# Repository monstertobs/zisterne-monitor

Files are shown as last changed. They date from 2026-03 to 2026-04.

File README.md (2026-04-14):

# 🏺 Zisterne Monitor

**Intelligente Zisternen-Wasserstandsüberwachung mit Raspberry Pi Zero 2W**

Ein vollständiges DIY-Projekt zur Überwachung des Füllstands einer Regenwasserzisterne – mit automatischer Installation, elegantem Web-Dashboard, 3D-gedrucktem Gehäuse und Wettervorhersage für den erwarteten Regenwasserzulauf.






---

## 💡 Die Idee

Ich habe eine Regenwasserzisterne im Garten, die Wasser vom Hausdach sammelt. Das Wasser wird zum Gießen und für andere Zwecke genutzt. Das Problem: Man weiß nie genau wie voll die Zisterne ist – ohne hineinzuschauen.

Die Idee war ein **vollautomatisches, selbst gehostetes Überwachungssystem** das:
- Den Wasserstand präzise misst
- Ein elegantes Dashboard im Browser zeigt
- Auf dem eigenen Heimnetzwerk läuft (keine Cloud, keine Abos)
- Komplett selbst nachgebaut werden kann

---

## ✨ Features

### Dashboard
- 🏺 **3D Erdquerschnitt** – animierte Zisterne mit Wasserstand, Blasen und Wellen
- 💧 **Liter-Anzeige** – aktueller Inhalt, Kapazität, Zu-/Abfluss seit letzter Messung
- 🔮 **Verbrauchsprognose** – wie viele Tage reicht der Vorrat noch?
- 🌧️ **Regenvorhersage** – 7-Tage-Vorhersage mit erwartetem Zulauf in Litern
- 📅 **Wochenverbrauch** – Durchschnitt pro Wochentag
- 🌧️ **Regenereignis-Erkennung** – automatische Erkennung von Regenfällen

### Installation & Betrieb
- ⚡ **Vollautomatische Installation** – SD-Karte vorbereiten, Pi einschalten, fertig
- 📡 **Captive Portal** – WLAN-Einrichtung per Smartphone wie im Hotel
- 🌐 **zisterne.local** – erreichbar über einfache URL im Heimnetz
- 📶 **WLAN-Verwaltung** – weitere Netzwerke direkt in den Einstellungen hinzufügen

### Hardware
- 🖨️ **3D-Druck Gehäuse** – für Pi Zero 2WH, druckfertige SCAD-Dateien
- 🔧 **Sensor-Halterung** – für DN25-Rohr oder Wandmontage mit Langlöchern
- 📏 **UART-Sensor** – SR04M-2 Ultraschallsensor (wasserdicht, robuste UART-Kommunikation)

---

## 🛒 Einkaufsliste

| Bauteil | Beschreibung | Preis ca. |
|---|---|---|
| Raspberry Pi Zero 2 WH | Mit vorgelötetem GPIO-Header | ~18 € |
| SR04M-2 | Wasserdichter Ultraschallsensor mit UART | ~8 € |
| MicroSD 32GB | SanDisk Extreme A1 | ~9 € |
| Micro-USB Netzteil 5V/2A | Für den Pi | ~8 € |
| 1 kΩ Widerstand | Spannungsteiler Sensor-TX → Pi-RX | < 1 € |
| 2 kΩ Widerstand | Spannungsteiler Sensor-TX → Pi-RX | < 1 € |
| JY(ST)Y 2×2×0,8 mm | KNX/EIB Kabel für Sensor (bis 10 m) | ~10 € |
| **Gesamt** | | **~55 €** |

---

## 🔌 Verkabelung

Der SR04M-2 kommuniziert über **UART** (seriell) – kein GPIO-Triggern nötig, der Sensor sendet automatisch alle ~100 ms einen Abstandswert.

```
SR04M-2 Sensor              Spannungsteiler        Pi Zero 2 WH
──────────────              ───────────────        ────────────
VCC  ──────────────────────────────────────────── Pin 2  (5V)
GND  ──────────────────────────────────────────── Pin 6  (GND)
TX   ──── 1 kΩ ──── Punkt A ──── 2 kΩ ──── GND (Pin 9)
                        │
                        └──────────────────────── Pin 10 (GPIO 15 / RXD)
RX   ── (nicht angeschlossen – Auto-Output-Modus)
```

> ⚠️ **Wichtig:** Der Sensor-TX liefert 5 V – der Pi verträgt nur 3,3 V!
> Der Spannungsteiler (1 kΩ / 2 kΩ) ist **Pflicht** und schützt den UART-Eingang.

**Kabelempfehlung:** JY(ST)Y 2×2×0,8 mm (KNX/EIB-Kabel) – bis 10 m problemlos nutzbar.

---

## 🚀 Installation (vollständig headless)

### Schritt 1 – SD-Karte vorbereiten

1. **Raspberry Pi Imager** herunterladen: [raspberrypi.com/software](https://www.raspberrypi.com/software/)
2. Flashen mit:
   - **Gerät:** Raspberry Pi Zero 2W
   - **OS:** Raspberry Pi OS Lite (64-bit, Bookworm)
   - **Einstellungen (Zahnrad ⚙️):** Hostname `zisterne`, SSH aktivieren, Benutzer `pi`, Passwort setzen
3. Nach dem Flashen SD-Karte **neu einstecken** → `bootfs` erscheint im Finder/Explorer
4. Folgende Dateien in das **Root-Verzeichnis** von `bootfs` kopieren:
   - `Software/firstboot.sh`
   - `Software/app.py`
5. `bootfs/cmdline.txt` mit einem **Texteditor** öffnen (auf dem Mac: TextEdit → Format → Als reinen Text!)
   Ans Ende der **einzigen Zeile** anhängen *(mit Leerzeichen davor!)*:
   ```
    systemd.run=/boot/firmware/firstboot.sh
   ```
   > ⚠️ Keine neue Zeile anfangen – alles muss in **einer einzigen Zeile** bleiben!

### Schritt 2 – Pi starten und WLAN einrichten

1. SD-Karte in den Pi einlegen, Strom anschließen
2. Nach ~30 Sekunden erscheint der Hotspot **`Zisterne-Setup`** (Passwort: `zisterne123`)
3. Mit dem Smartphone verbinden → das Portal öffnet sich automatisch
4. WLAN-Name und Passwort des Heimnetzes eingeben → Pi verbindet sich
5. Nach ~5 Minuten ist alles fertig

### Schritt 3 – Dashboard aufrufen

```
http://zisterne.local
```
oder direkt über die IP-Adresse aus dem Router.

> **Tipp:** Beim ersten Start gleich die **Kalibrierung** aufrufen (Tab oben) und die tatsächliche Zisternentiefe einstellen.

---

## ⚙️ Konfiguration

Nach der Installation im Browser unter **Einstellungen** konfigurieren:

| Einstellung | Beschreibung | Standard |
|---|---|---|
| Name | Anzeigename im Dashboard | Zisterne Garten |
| Kapazität | Maximaler Inhalt in Litern | 5.000 L |
| Tiefe | Zisternentiefe in cm | 240 cm |
| Min-Abstand | Toter Bereich über dem Boden | 25 cm |
| Messintervall | Sekunden zwischen Messungen | 60 s |
| Dachfläche | Fläche für Regenvorhersage | 100 m² |
| Abflusskoeffizient | Anteil Regenwasser der ankommt | 0,8 |
| Standort GPS | Für Wettervorhersage | 50.11°N, 8.68°O |

---

## 🖨️ 3D-Druck

Alle SCAD-Dateien sind in `3D_Druck/SCAD/` zu finden und direkt in **OpenSCAD** renderbar:

| Datei | Beschreibung |
|---|---|
| `1_Gehaeuse_Unterteil.scad` | Pi Zero 2WH Gehäuse Unterteil |
| `2_Gehaeuse_Deckel.scad` | Gehäuse Deckel |
| `3_Sensor_Rohrhalterung_DN25.scad` | Halterung für DN25-Rohr |
| `4_Sensor_Wandhalterung.scad` | Halterung für Betonwand (Langlöcher) |

**Druckeinstellungen:**
- Schichthöhe: 0,2 mm
- Wandlinien: 4
- Infill: 20–40 %
- Material: PLA (Gehäuse) oder PETG (Sensorhalterung, feuchtigkeitsbeständig)

---

## 🌐 API-Endpunkte

Das Dashboard läuft als Flask-Server und stellt folgende API bereit:

| Endpoint | Beschreibung |
|---|---|
| `GET /api/aktuell` | Aktuelle Messung (Abstand, Füllstand, Uhrzeit) |
| `GET /api/range?h=24` | Verlauf (h=Stunden, d=Tage, m=Monate) |
| `GET /api/liter` | Aktueller Inhalt in Litern + Zu-/Abfluss |
| `GET /api/liter/verlauf` | Stündliche Liter-Werte heute |
| `GET /api/prognose` | Verbrauchsprognose in Tagen |
| `GET /api/regen` | Erkannte Regenereignisse |
| `GET /api/woche` | Ø Verbrauch pro Wochentag |
| `GET /api/wetter` | 7-Tage Regenvorhersage (Open-Meteo) |
| `GET /api/wifi` | WLAN-Status + Signalstärke |
| `GET /api/version` | Versionsinformation |

---

## 🏗️ Technischer Stack

```
Raspberry Pi Zero 2W
├── Raspberry Pi OS Lite 64-bit (Bookworm)
├── Python 3
│   ├── Flask          – Web-Dashboard (Port 80)
│   ├── APScheduler    – Automatische Messungen (alle 60 s)
│   ├── pyserial       – UART-Kommunikation mit SR04M-2
│   └── SQLite         – Messdaten-Datenbank (daten.db)
├── NetworkManager     – WLAN-Verwaltung + Captive Portal
└── avahi-daemon       – zisterne.local mDNS
```

**Frontend:** Reines HTML/CSS/JavaScript – keine Frameworks, keine npm, läuft direkt im Browser.

**Wetterdaten:** [Open-Meteo](https://open-meteo.com/) – kostenlos, kein API-Key, DSGVO-konform.

---

## 📁 Repository-Struktur

```
zisterne-monitor/
├── Software/
│   ├── app.py              # Flask-Webserver + Dashboard (alle Templates inline)
│   └── firstboot.sh        # Automatisches Erststart-Skript (headless Setup)
├── 3D_Druck/
│   └── SCAD/               # OpenSCAD Quelldateien für Gehäuse + Halterungen
├── docs/                   # Dokumentation
├── VERSION                 # Changelog
├── .gitignore
└── README.md
```

---

## 🔄 Updates einspielen

```bash
# Vom Mac auf den Pi kopieren (Pi muss im Heimnetz sein):
scp Software/app.py pi@zisterne.local:/home/pi/zisterne/app.py

# Dienst neu starten:
ssh pi@zisterne.local "sudo systemctl restart zisterne.service"
```

---

## 📊 Versions-Historie

Siehe [VERSION](VERSION) für den vollständigen Changelog.

| Version | Highlights |
|---|---|
| v0.7.0 | UART Auto-Output-Modus, robuste Port-Verwaltung, vollständige Doku-Überarbeitung |
| v0.6.x | SR04M-2 UART Sensor, pyserial statt RPi.GPIO, Captive Portal Fixes |
| v0.5.0 | Regenvorhersage, 3D Erdquerschnitt-Visualisierung, WLAN-Verwaltung |
| v0.3.x | Verbrauchsprognose, Regenerkennung, Wochenverbrauch |
| v0.2.0 | Liter-Anzeige, Kapazitäts-Einstellung |
| v0.1.0 | Initiale Version: Dashboard, Dark Mode, SQLite |

---

## 🤝 Beitragen

Pull Requests sind willkommen! Bei größeren Änderungen bitte zuerst ein Issue öffnen.

1. Fork erstellen
2. Feature-Branch: `git checkout -b feature/mein-feature`
3. Änderungen committen: `git commit -m 'Add: mein Feature'`
4. Push: `git push origin feature/mein-feature`
5. Pull Request erstellen

---

## 📄 Lizenz

MIT License – siehe [LICENSE](LICENSE)

---

## 👤 Autor

**Tobias Meier**
📧 admin(at)secutobs.com
🌐 [github.com/monstertobs](https://github.com/monstertobs)

## ☕ Support

If you find this project useful and want to say thanks, feel free to send a small donation in Bitcoin:
**BTC:** 1ADFsY95oPRvVQ36yWcud8zM4qzZZDqf6F
No pressure – a GitHub ⭐ star is also very much appreciated!

---

*Entwickelt mit ❤️ für alle, die ihre Zisterne im Blick behalten wollen.*

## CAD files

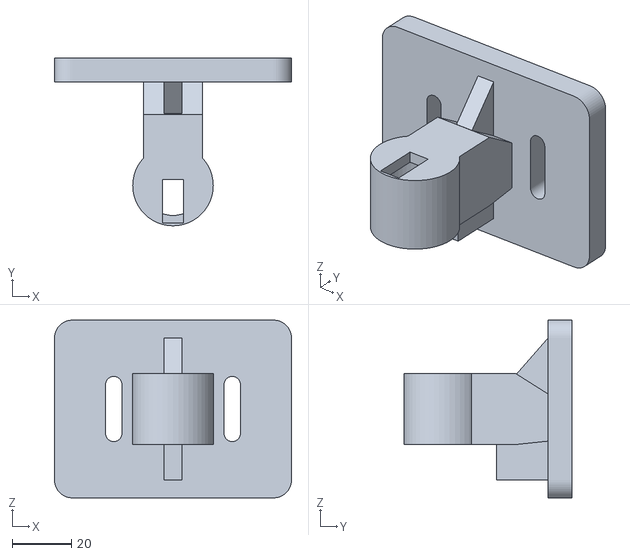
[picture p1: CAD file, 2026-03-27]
zisterne-monitor-v0.7.0/3D_Druck/sensor_wandhalterung_korrigiert_plan_mit_langloch_v2.stl
80.0 x 56.6 x 60.0

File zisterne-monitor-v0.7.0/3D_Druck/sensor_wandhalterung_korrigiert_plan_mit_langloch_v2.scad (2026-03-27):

// ╔══════════════════════════════════════════════════════════╗
// ║  JSN-SR04T Sensor-Wandhalterung                         ║
// ║  Montage an Betonwand mit Langlöchern                   ║
// ║  Sensor zeigt nach UNTEN in die Zisterne               ║
// ║  Tobias Meier · admin@secutobs.com · v0.5.0            ║
// ╠══════════════════════════════════════════════════════════╣
// ║  DRUCKEN:                                              ║
// ║  1. F6 → rendern  2. File → Export → STL              ║
// ║  Material:  PETG (feuchtigkeitsbeständig, empfohlen)   ║
// ║            oder PLA für trockene Umgebung              ║
// ║  Schichthöhe: 0.2mm | Wandlinien: 4 | Infill: 40%    ║
// ║  Support:  NEIN – druckfreundlich ausgerichtet         ║
// ║  Ausrichtung: Rückwand flach auf Druckbett             ║
// ╠══════════════════════════════════════════════════════════╣
// ║  MONTAGE:                                              ║
// ║  1. Halterung an Betonwand halten, Position markieren  ║
// ║  2. 2× Dübel setzen (6mm Universaldübel)              ║
// ║  3. Schraube M4×30 oder 4mm Holzschraube verwenden    ║
// ║  4. Langlöcher erlauben ±15mm vertikale Justage       ║
// ║  5. Sensor von unten in Aufnahme drücken (Pressfit)   ║
// ║  6. Sensor schwenkbar: Winkel 0°-30° einstellbar      ║
// ╚══════════════════════════════════════════════════════════╝

// ── Sensor JSN-SR04T ─────────────────────────────────────
SENS_D   = 19.4;    // angepasst    // Sensorkopf Durchmesser
SENS_SP  =  0.4;    // angepasst    // Pressfit-Spiel
SENS_T   = 20.0;    // angepasst    // Einbautiefe Sensor
WAND_S   =  3.5;    // Wandstärke Sensoraufnahme

// ── Wandplatte ───────────────────────────────────────────
WP_B     = 80.0;    // Breite Wandplatte
WP_H     = 60.0;    // Höhe Wandplatte
WP_T     =  8.0;    // Tiefe/Dicke Wandplatte

// ── Langlöcher ───────────────────────────────────────────
LL_B     =  5.5;    // Breite Langloch (für M4/4mm Schraube)
LL_H     = 22.0;    // Höhe Langloch  (±11mm Justage)
LL_X     = 20.0;    // Abstand Langloch von Mitte (je Seite)
LL_Y     =  0.0;    // Vertikale Position (Mitte der Platte)
LL_SR    =  LL_B/2; // Eckenradius Langloch

// ── Sensorarm ────────────────────────────────────────────
ARM_L    = 35.0;    // Armlänge (Abstand Wand → Sensormitte)
ARM_B    = 20.0;    // Armbreite
ARM_T    = 24.0;    // angepasst für 20 mm Sensorhöhe    // Armtiefe

// ── Sensor-Aufnahme ──────────────────────────────────────
SENS_R   = SENS_D/2 + SENS_SP;
AUFN_RA  = SENS_R + WAND_S;

// ── Versteifungsrippe ────────────────────────────────────
RIP_T    =  6.0;    // Rippendicke
RIP_H    = 30.0;    // Rippenhöhe

// Korrigierte Version:
// - ursprüngliche Form bleibt erhalten
// - Sensor auf 19.4 x 20 mm angepasst
// - Langlöcher wieder vorhanden
// - mittlerer Rückseiten-Überstand entfernt
// - keine Rückseiten-Versenkungen / Gewichtsfenster
// - Langlöcher vollständig durch die Platte verlängert
$fn = 48;

// ════════════════════════════════════════════════════════
//  WANDHALTERUNG – alles in einem Teil
// ════════════════════════════════════════════════════════
difference() {
    union() {

        // ── 1. WANDPLATTE ────────────────────────────────
        hull() {
            for(x = [-WP_B/2+6, WP_B/2-6])
            for(z = [-WP_H/2+6, WP_H/2-6])
                translate([x, 0, z])
                    rotate([90,0,0])
                        cylinder(r=6, h=WP_T);
        }

        // ── 2. SENSORARM (nach vorne und unten) ──────────
        // Arm geht von Mitte der Platte nach vorne
        hull() {
            // Verbindung zur Platte (unten-mitte)
            translate([-ARM_B/2, -ARM_T, -10])
                cube([ARM_B, ARM_T, 10]);
            // Arm-Ende (weiter vorne)
            translate([-ARM_B/2, -(WP_T + ARM_L), -ARM_T/2])
                cube([ARM_B, ARM_T, ARM_T]);
        }

        // ── 3. SENSOR-AUFNAHME (am Arm-Ende, Sensor nach unten) ──
        translate([0, -(WP_T + ARM_L), 0])
            cylinder(h=ARM_T+0.1, r=AUFN_RA, center=true);

        // ── 4. VERSTEIFUNGSRIPPEN ────────────────────────
        // intersection() begrenzt Rippen auf y<=0 → Rückwand bleibt flach
        intersection() {
            union() {
                hull(){
                    translate([-RIP_T/2, -WP_T, WP_H/2-6-RIP_H])
                        cube([RIP_T, RIP_T, RIP_H]);
                    translate([-RIP_T/2, -(WP_T+ARM_L*0.6), -8])
                        cube([RIP_T, RIP_T, 8]);
                }
                hull(){
                    translate([-RIP_T/2, -WP_T, -WP_H/2+6])
                        cube([RIP_T, WP_T+2, RIP_H]);
                    translate([-RIP_T/2, -(WP_T+ARM_L*0.5), -WP_H/2+6])
                        cube([RIP_T, 6, 16]);
                }
            }
            // Nur Bereich VOR der Rückwand (y <= 0)
            translate([-500, -500, -500]) cube([1000, 500, 1000]);
        }
    }

    // ── BOHRUNGEN ────────────────────────────────────────

    // Langloch Links
    translate([-LL_X, -WP_T/2, LL_Y])
        rotate([90,0,0]) {
            hull() {
                translate([0,  LL_H/2-LL_SR, 0]) cylinder(r=LL_SR, h=WP_T+20, center=true);
                translate([0, -LL_H/2+LL_SR, 0]) cylinder(r=LL_SR, h=WP_T+20, center=true);
            }
        }

    // Langloch Rechts
    translate([LL_X, -WP_T/2, LL_Y])
        rotate([90,0,0]) {
            hull() {
                translate([0,  LL_H/2-LL_SR, 0]) cylinder(r=LL_SR, h=WP_T+20, center=true);
                translate([0, -LL_H/2+LL_SR, 0]) cylinder(r=LL_SR, h=WP_T+20, center=true);
            }
        }

    // Sensor-Bohrung (von unten, Pressfit)
    translate([0, -(WP_T + ARM_L), -(ARM_T/2)-0.1])
        cylinder(h=ARM_T-WAND_S+0.1, r=SENS_R);

    // Einführphase Sensor
    translate([0, -(WP_T + ARM_L), -(ARM_T/2)-2])
        cylinder(h=2.1, r1=SENS_R+2, r2=SENS_R);

    // Kabel-Nut (Kabel kommt seitlich raus und nach oben)
    translate([-3.5, -(WP_T + ARM_L + AUFN_RA - 1), ARM_T*0.1])
        cube([7, AUFN_RA+1, ARM_T]);
}

// ════════════════════════════════════════════════════════
//  LANGLOCH-ERKLÄRUNG
// ════════════════════════════════════════════════════════
// Langlöcher: 5.5mm × 22mm
// → Schraube M4 oder Dübel 6mm + Schraube 4mm
// → ±11mm Verstellbereich vertikal
// → Schraubenkopf versenkt (bündig mit Wandplatte)
//
// SENSOR-AUSRICHTUNG:
// → Sensor drückt von UNTEN in die Aufnahme
// → Durch Verschieben der Halterung an der Wand
//   kann der Sensor exakt ausgerichtet werden
// → Für horizontale Justage: Dübellöcher entsprechend setzen

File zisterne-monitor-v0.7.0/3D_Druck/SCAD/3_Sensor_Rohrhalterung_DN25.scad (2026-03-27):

// ╔══════════════════════════════════════════════════════════╗
// ║  JSN-SR04T Sensorhalterung                              ║
// ║  Vertikales Rohr DN25 · Sensor zeigt nach unten        ║
// ║  Tobias Meier · admin@secutobs.com · v0.2.0            ║
// ╠══════════════════════════════════════════════════════════╣
// ║  DRUCKEN:                                              ║
// ║  1. F6 → rendern  2. File → Export → STL              ║
// ║  Material:  PETG oder PLA                              ║
// ║  Schichthöhe: 0.2mm | Wandlinien: 4 | Infill: 40%    ║
// ║  Support: JA – von Bett                                ║
// ║  Ausrichtung: Klammer steht senkrecht auf dem Bett     ║
// ╚══════════════════════════════════════════════════════════╝

// ── Rohr-Durchmesser anpassen ────────────────────────────
ROHR_D = 32;   // DN25 = 32mm Außendurchmesser
               // DN20 = 25mm | DN32 = 40mm | DN40 = 50mm

// ── Sensor JSN-SR04T ─────────────────────────────────────
SENS_D  = 22.0;   // Sensorkopf Außendurchmesser
SENS_SP =  0.4;   // Pressfit-Spiel
SENS_T  = 13.0;   // Einbautiefe

// ── Kabelbinder ──────────────────────────────────────────
KB_B    =  5.0;   // Breite Kabelbinder-Schlitz
KB_ABST = 22.0;   // Abstand der zwei Schlitze
WAND_C  =  3.5;   // Wandstärke Klammer

// ── Berechnung ───────────────────────────────────────────
ROHR_R  = ROHR_D / 2;
CLIP_RA = ROHR_R + WAND_C;           // Klammer Außenradius
CLIP_H  = KB_ABST + KB_B*2 + 10;    // Klammerhöhe gesamt
SENS_R  = SENS_D/2 + SENS_SP;        // Sensoraufnahme Innenradius
AUFN_RA = SENS_R + 3.5;              // Sensoraufnahme Außenradius

// Arm-Geometrie
ARM_B   = 16;    // Arm-Querschnitt Breite
ARM_H   = 14;    // Arm-Querschnitt Höhe
// Arm startet mittig an der Klammer
ARM_Z   = (CLIP_H - ARM_H) / 2;
// Sensor hängt unter dem Arm
SENS_Z  = ARM_Z - SENS_T - 10;
// X-Abstand Rohrmitte → Sensormitte
OFFS_X  = CLIP_RA + ARM_B + AUFN_RA + 2;

$fn = 48;

// ════════════════════════════════════════════════════════
//  ALLES IN EINEM union() – verhindert lose Teile!
// ════════════════════════════════════════════════════════
difference() {
    union() {

        // ── 1. ROHRKLAMMER ───────────────────────────────
        // C-förmiger Ring um das Rohr
        difference() {
            cylinder(h=CLIP_H, r=CLIP_RA);
            // Rohrbohrung
            translate([0,0,-0.1])
                cylinder(h=CLIP_H+0.2, r=ROHR_R);
            // C-Öffnung nach hinten (neg. Y)
            OE = ROHR_R * 0.7;
            translate([-OE/2, -CLIP_RA-0.1, -0.1])
                cube([OE, CLIP_RA+0.2, CLIP_H+0.2]);
        }

        // ── 2. HORIZONTALER ARM ──────────────────────────
        // Verbindet Klammer mit Sensoraufnahme
        // Direkt mit hull() an Klammer angebunden → KEINE losen Teile
        hull() {
            // An der Klammer-Außenwand
            translate([CLIP_RA-1, -ARM_B/2, ARM_Z])
                cube([1, ARM_B, ARM_H]);
            // An der Sensorseite
            translate([OFFS_X-AUFN_RA-ARM_B, -ARM_B/2, ARM_Z])
                cube([ARM_B, ARM_B, ARM_H]);
        }

        // ── 3. VERTIKALER STEG ───────────────────────────
        // Führt Sensoraufnahme nach unten
        // hull() verbindet Arm und Sensoraufnahme → EIN Teil
        hull() {
            // Oben: Ende des Horizontalarms
            translate([OFFS_X-AUFN_RA-ARM_B, -ARM_B/2, ARM_Z])
                cube([ARM_B, ARM_B, ARM_H]);
            // Unten: über der Sensoraufnahme
            translate([OFFS_X-AUFN_RA-4, -ARM_B/2, SENS_Z+SENS_T-2])
                cube([4, ARM_B, 2]);
        }

        // ── 4. SENSORAUFNAHME ────────────────────────────
        // Zylindrische Aufnahme für Sensor (Pressfit von unten)
        // Mit hull() an Steg angebunden → EIN Teil
        hull() {
            // Verbindung zum Steg
            translate([OFFS_X-AUFN_RA-4, -ARM_B/2, SENS_Z+SENS_T-2])
                cube([4, ARM_B, 2]);
            // Aufnahmezylinder oben
            translate([OFFS_X, 0, SENS_Z+SENS_T])
                cylinder(h=0.5, r=AUFN_RA);
        }
        // Eigentlicher Aufnahmezylinder
        translate([OFFS_X, 0, SENS_Z])
            cylinder(h=SENS_T, r=AUFN_RA);

        // ── 5. VERSTEIFUNGSRIPPE ─────────────────────────
        // Dreieck-Rippe unter dem Arm für Stabilität
        hull() {
            translate([CLIP_RA-0.5, -2, ARM_Z])
                cube([1, 4, 3]);
            translate([OFFS_X-AUFN_RA-ARM_B-1, -2, ARM_Z+ARM_H*0.6])
                cube([1, 4, 3]);
        }

    } // end union()

    // ── BOHRUNGEN (außerhalb union, schneidet alles) ─────

    // Sensor-Bohrung von unten (Pressfit)
    translate([OFFS_X, 0, SENS_Z-0.1])
        cylinder(h=SENS_T-3+0.1, r=SENS_R);

    // Einführphase unten (erleichtert Einsetzen)
    translate([OFFS_X, 0, SENS_Z-1.5])
        cylinder(h=1.6, r1=SENS_R+2.0, r2=SENS_R);

    // Kabel-Nut seitlich (Kabel nach oben führen)
    translate([OFFS_X-3, -AUFN_RA-0.1, SENS_Z+SENS_T*0.3])
        cube([6, AUFN_RA+0.2, SENS_T*0.8]);

    // Kabelbinder-Schlitz 1 (unterer)
    translate([0, 0, 5])
        kb_schlitz_bohrung(CLIP_RA, KB_B);

    // Kabelbinder-Schlitz 2 (oberer)
    translate([0, 0, 5+KB_ABST])
        kb_schlitz_bohrung(CLIP_RA, KB_B);

} // end difference()


// ── Kabelbinder-Schlitz als Modul ────────────────────────
module kb_schlitz_bohrung(r, breite) {
    difference() {
        cylinder(h=breite, r=r+0.1);
        translate([0, 0, -0.1])
            cylinder(h=breite+0.2, r=r-WAND_C+0.2);
        // C-Öffnung nach hinten freilassen
        OE = ROHR_R * 0.7 + 1;
        translate([-OE/2, -r-0.2, -0.2])
            cube([OE, r+0.4, breite+0.4]);
    }
}

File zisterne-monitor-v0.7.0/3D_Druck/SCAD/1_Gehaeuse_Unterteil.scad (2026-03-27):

// ╔══════════════════════════════════════════════════════════╗
// ║  Pi Zero 2 WH Gehäuse – UNTERTEIL                       ║
// ║  Tobias Meier · admin@secutobs.com · v0.2.0             ║
// ╠══════════════════════════════════════════════════════════╣
// ║  DRUCKEN:                                               ║
// ║  1. F6 → rendern  2. File → Export → STL               ║
// ║  Material:  PLA  |  Schichthöhe: 0.2mm                 ║
// ║  Wandlinien: 4   |  Infill: 20%  |  Support: NEIN      ║
// ╚══════════════════════════════════════════════════════════╝

// ── Platinen-Maße Pi Zero 2W ─────────────────────────────
PI_L   = 65.0;   // Platinenlänge
PI_B   = 30.0;   // Platinenbreite
SPIEL  =  0.5;   // Spiel ringsrum

// ── Gehäuse-Parameter ───────────────────────────────────
WAND   =  2.5;   // Wandstärke
BODEN  =  1.8;   // Bodenstärke
H_INNEN = 14.0;  // Innenhöhe (Platine ~5mm + Bauteile + Luft)
R_ECKE =  3.0;   // Eckenradius

// ── Berechnete Maße ──────────────────────────────────────
IN_L = PI_L + SPIEL*2;    // Innenmaß Länge
IN_B = PI_B + SPIEL*2;    // Innenmaß Breite
AU_L = IN_L + WAND*2;     // Außenmaß Länge  = ~73mm
AU_B = IN_B + WAND*2;     // Außenmaß Breite = ~37mm
AU_H = H_INNEN + BODEN;   // Außenhöhe gesamt

// ── Pi Zero Lochpositionen (von Platinen-Ursprung) ───────
// Löcher: 3.5mm Ø, Raster 58 x 23mm (Mitte-zu-Mitte)
L_X1 = WAND + SPIEL + 3.5;
L_X2 = WAND + SPIEL + 3.5 + 58.0;
L_Y1 = WAND + SPIEL + 3.5;
L_Y2 = WAND + SPIEL + 3.5 + 23.0;

// ── Port-Positionen (von Platinen-Kante gemessen) ────────
// Rechte Seite: PWR (Micro-USB) und OTG (Micro-USB)
// Pi Zero: PWR bei X≈54mm, OTG bei X≈41mm (von links)
PWR_X  = WAND + SPIEL + 54.5;   // Mitte PWR-USB
OTG_X  = WAND + SPIEL + 41.5;   // Mitte OTG-USB
USB_B  =  9.0;   // Breite Micro-USB Ausschnitt
USB_H  =  4.0;   // Höhe  Micro-USB Ausschnitt
USB_Z  =  BODEN; // USB liegt direkt auf Boden-Level

// Linke Seite: Mini-HDMI bei X≈12mm
HDMI_X = WAND + SPIEL + 12.0;
HDMI_B = 12.0;
HDMI_H =  4.5;

// Vorne (kurze Seite, wo SD-Karte): SD bei Y≈1mm
SD_X   = WAND + SPIEL + 1.0;
SD_B   = 13.0;
SD_H   =  2.2;

// ── Lüftungsschlitze Boden ───────────────────────────────
// Schmal und kurz → kein Durchhängen
SLOT_B = 2.5;    // Breite Schlitz (schmal!)
SLOT_H = IN_B * 0.6;  // Länge
SLOT_Z = BODEN;

$fn = 40;

// ════════════════════════════════════════════════════════
//  UNTERTEIL
// ════════════════════════════════════════════════════════
module gehaeuse_unterteil() {
    difference() {
        // ── Grundkörper mit abgerundeten Ecken ──────────
        hull() {
            for(x = [R_ECKE, AU_L - R_ECKE])
            for(y = [R_ECKE, AU_B - R_ECKE])
                translate([x, y, 0])
                    cylinder(r=R_ECKE, h=AU_H, $fn=32);
        }

        // ── Innenraum ───────────────────────────────────
        translate([WAND, WAND, BODEN])
            cube([IN_L, IN_B, H_INNEN + 0.1]);

        // ── Port-Ausschnitte ────────────────────────────

        // PWR Micro-USB (rechte kurze Seite)
        translate([PWR_X - USB_B/2, AU_B - WAND - 0.1, USB_Z])
            cube([USB_B, WAND + 0.2, USB_H]);

        // OTG Micro-USB (rechte kurze Seite)
        translate([OTG_X - USB_B/2, AU_B - WAND - 0.1, USB_Z])
            cube([USB_B, WAND + 0.2, USB_H]);

        // Mini-HDMI (linke kurze Seite)
        translate([HDMI_X - HDMI_B/2, -0.1, USB_Z])
            cube([HDMI_B, WAND + 0.2, HDMI_H]);

        // SD-Karte (lange Seite vorne, links)
        translate([-0.1, SD_X, BODEN - 0.1])
            cube([WAND + 0.2, SD_B, SD_H]);

        // ── Schraublöcher in Ecken (M2.5) ───────────────
        // Option: Gehäuse kann mit Schrauben geschlossen werden
        for(x = [L_X1, L_X2])
        for(y = [L_Y1, L_Y2])
            translate([x, y, -0.1])
                cylinder(r=1.4, h=BODEN + 0.2, $fn=16);

        // ── Lüftungsschlitze Boden (schmal, kein Support) ─
        for(i = [0:5])
            translate([WAND + 4 + i * 9, (AU_B - SLOT_H)/2, -0.1])
                cube([SLOT_B, SLOT_H, BODEN + 0.2]);
    }

    // ── Montagepfosten innen ─────────────────────────────
    // Platine liegt auf diesen Pfosten auf (Höhe = 2mm)
    for(x = [L_X1, L_X2])
    for(y = [L_Y1, L_Y2]) {
        translate([x, y, BODEN])
            cylinder(r=2.8, h=2.0, $fn=20);
        // Sackloch für M2 Schraube (optional)
        translate([x, y, BODEN - 0.1])
            cylinder(r=1.0, h=2.2, $fn=16);
    }

    // ── Clip-Nasen für Deckel (je 2× links/rechts) ───────
    for(x = [AU_L*0.28, AU_L*0.72]) {
        translate([x - 2, -0.1, AU_H - 4])
            cube([4, 1.6, 4]);
        translate([x - 2, AU_B - 1.5, AU_H - 4])
            cube([4, 1.6, 4]);
    }
}

gehaeuse_unterteil();

// ════════════════════════════════════════════════════════
//  PORT-REFERENZ
// ════════════════════════════════════════════════════════
// Ausrichtung auf dem Druckbett: Boden nach unten
// Die Öffnungen sind:
//   Kurze Seite hinten (Y=AU_B): PWR + OTG Micro-USB
//   Kurze Seite vorne (Y=0):     Mini-HDMI
//   Lange Seite links (X=0):     SD-Karten-Schlitz

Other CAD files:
zisterne-monitor-v0.7.0/3D_Druck/SCAD/4_Sensor_Wandhalterung.scad
zisterne-monitor-v0.7.0/3D_Druck/SCAD/2_Gehaeuse_Deckel.scad

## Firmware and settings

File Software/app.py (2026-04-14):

#!/usr/bin/env python3
"""
╔══════════════════════════════════════════════════════════╗
║              ZISTERNE MONITOR                            ║
║  Raspberry Pi Zero 2W + SR04M-2 UART Ultraschallsensor  ║
╠══════════════════════════════════════════════════════════╣
║  Version:  0.7.8                                         ║
║  Datum:    2026-04-14                                    ║
║  Autor:    Tobias Meier                                  ║
║  E-Mail:   admin@secutobs.com                            ║
╚══════════════════════════════════════════════════════════╝
"""

# ── Versionsinformation ──────────────────────────────────────
__version__     = "0.7.9"
__version_date__ = "2026-04-14"
__author__      = "Tobias Meier"
__email__       = "admin@secutobs.com"
__project__     = "Zisterne Monitor"
# ─────────────────────────────────────────────────────────────

import time, sqlite3, os, json, shutil, subprocess, urllib.request, shlex
from datetime import datetime, timedelta
from flask import Flask, render_template_string, jsonify, request, redirect
from apscheduler.schedulers.background import BackgroundScheduler

BASE_DIR = os.path.dirname(os.path.abspath(__file__))
DB_PFAD  = os.path.join(BASE_DIR, "daten.db")
CFG_PFAD = os.path.join(BASE_DIR, "config.json")

DEFAULT_CFG = {
    "name":          "Zisterne Garten",
    "tiefe_cm":      240,
    "min_cm":        25,
    "intervall_sek": 60,
    "serial_port":   "/dev/serial0",
    "warnung_leer":  20,
    "warnung_voll":  90,
    "kapazitaet_l":  5000,
    "dachflaeche_m2": 100,
    "standort_lat":  50.11,
    "standort_lon":   8.68,
    "abfluss_koeff":  0.8,
}

def cfg_laden():
    if os.path.exists(CFG_PFAD):
        with open(CFG_PFAD) as f:
            return {**DEFAULT_CFG, **json.load(f)}
    return DEFAULT_CFG.copy()

def cfg_speichern(c):
    with open(CFG_PFAD,'w') as f:
        json.dump(c, f, indent=2, ensure_ascii=False)

CFG = cfg_laden()
cfg_speichern(CFG)

_ser = None
SERIAL_OK = False
import threading as _threading
_ser_lock = _threading.Lock()
try:
    import serial as _serial
except Exception:
    _serial = None

def _open_serial():
    global _ser, SERIAL_OK
    if _serial is None:
        _ser = None
        SERIAL_OK = False
        return False
    try:
        _ser = _serial.Serial(CFG["serial_port"], 9600, timeout=0.35)
        try:
            _ser.reset_input_buffer()
            _ser.reset_output_buffer()
        except Exception:
            pass
        SERIAL_OK = True
        return True
    except Exception as e:
        _ser = None
        SERIAL_OK = False
        print("⚠  Serieller Port nicht verfügbar:", e)
        return False

def _close_serial():
    global _ser, SERIAL_OK
    try:
        if _ser is not None:
            _ser.close()
    except Exception:
        pass
    _ser = None
    SERIAL_OK = False

def _reopen_serial():
    _close_serial()
    time.sleep(0.1)
    return _open_serial()

_open_serial()

# ── Auto-Update ───────────────────────────────────────────────────────────────
_GITHUB_API_URL = "https://api.github.com/repos/monstertobs/zisterne-monitor/releases/latest"
_GITHUB_RAW_URL = "https://raw.githubusercontent.com/monstertobs/zisterne-monitor/main/Software/app.py"
_UPDATE_STATUS  = {"state": "idle", "message": "Bereit", "progress": 0, "latest": None}
# ─────────────────────────────────────────────────────────────────────────────

app = Flask(__name__)
scheduler = BackgroundScheduler()

def db_init():
    with sqlite3.connect(DB_PFAD) as c:
        c.execute("""CREATE TABLE IF NOT EXISTS messungen (
            id INTEGER PRIMARY KEY AUTOINCREMENT,
            zeitpunkt TEXT NOT NULL,
            abstand REAL, fuellstand REAL, wasser_cm REAL)""")
        c.commit()

def db_speichern(a, f, w):
    with sqlite3.connect(DB_PFAD) as c:
        c.execute("INSERT INTO messungen (zeitpunkt,abstand,fuellstand,wasser_cm) VALUES (?,?,?,?)",
            (datetime.now().isoformat(timespec='seconds'), a, f, w))
        c.commit()

def db_letzte():
    with sqlite3.connect(DB_PFAD) as c:
        r = c.execute("SELECT zeitpunkt,abstand,fuellstand,wasser_cm FROM messungen ORDER BY id DESC LIMIT 1").fetchone()
    return {"zeitpunkt":r[0],"abstand":r[1],"fuellstand":r[2],"wasser_cm":r[3]} if r else {}

def db_range(stunden=None, tage=None, monate=None):
    if monate:
        seit  = (datetime.now()-timedelta(days=monate*30)).isoformat()
        group = "strftime('%Y-%m',zeitpunkt)"
    elif tage:
        seit  = (datetime.now()-timedelta(days=tage)).isoformat()
        group = "DATE(zeitpunkt)"
    elif stunden:
        seit  = (datetime.now()-timedelta(hours=stunden)).isoformat()
        group = "strftime('%Y-%m-%dT%H:%M',zeitpunkt)" if stunden<=2 else "strftime('%Y-%m-%dT%H',zeitpunkt)"
    else:
        seit  = (datetime.now()-timedelta(hours=24)).isoformat()
        group = "strftime('%Y-%m-%dT%H',zeitpunkt)"
    with sqlite3.connect(DB_PFAD) as c:
        rows = c.execute(f"""
            SELECT {group} as t,
                   ROUND(AVG(fuellstand),1), ROUND(MIN(fuellstand),1),
                   ROUND(MAX(fuellstand),1), ROUND(AVG(wasser_cm),1)
            FROM messungen WHERE zeitpunkt>?
            GROUP BY t ORDER BY t ASC
        """, (seit,)).fetchall()
    return [{"t":r[0],"avg":r[1],"min":r[2],"max":r[3],"w":r[4]} for r in rows]

def db_roh(n=10):
    with sqlite3.connect(DB_PFAD) as c:
        rows = c.execute("SELECT zeitpunkt,abstand,fuellstand,wasser_cm FROM messungen ORDER BY id DESC LIMIT ?",(n,)).fetchall()
    return [{"t":r[0],"a":r[1],"f":r[2],"w":r[3]} for r in rows]

def _parse_uart_frame(buf):
    """Parst SR04M-2 UART-Frames: FF H L SUM"""
    while len(buf) >= 4:
        if buf[0] != 0xFF:
            buf.pop(0)
            continue
        h, l, s = buf[1], buf[2], buf[3]
        if ((0xFF + h + l) & 0xFF) == s:
            dist_mm = (h << 8) | l
            del buf[:4]
            return dist_mm
        buf.pop(0)
    return None

def abstand_messen():
    """
    Liest den SR04M-2 im UART-Auto-Output-Modus aus.
    Erwartetes Frame: FF H L SUM bei 9600 Baud.
    6000 mm wird als "außer Reichweite / kein Echo" verworfen.
    Gibt den Median gültiger Werte in cm zurück.
    """
    global _ser

    if _serial is None:
        return None

    if not _ser_lock.acquire(timeout=8):
        return None

    werte = []
    buf = bytearray()

    try:
        if _ser is None or not SERIAL_OK:
            if not _open_serial():
                return None

        try:
            _ser.reset_input_buffer()
        except Exception:
            pass

        start = time.time()

        while time.time() - start < 0.6:
            try:
                data = _ser.read(32)
                if data:
                    buf.extend(data)
                    while True:
                        dist_mm = _parse_uart_frame(buf)
                        if dist_mm is None:
                            break
                        if dist_mm == 6000:
                            continue
                        if 50 <= dist_mm <= 6000:
                            werte.append(dist_mm / 10.0)
            except Exception as e:
                print(f"⚠ UART Lesefehler, öffne Port neu: {e}")
                if not _reopen_serial():
                    return None
                buf = bytearray()

            time.sleep(0.03)
    finally:
        _ser_lock.release()

    if not werte:
        return None

    werte.sort()
    return round(werte[len(werte) // 2], 1)

def fuellstand(a):
    n=CFG["tiefe_cm"]-CFG["min_cm"]; w=CFG["tiefe_cm"]-a
    return round(max(0.0,min(100.0,(w/n)*100)),1), round(max(0,w),1)

def messen():
    a=abstand_messen()
    if a is None: return
    f,w=fuellstand(a); db_speichern(round(a,1),f,w)
    print(f"[{datetime.now().strftime('%H:%M:%S')}] {f}% | {w}cm | {a:.1f}cm")

def _update_worker():
    """Hintergrund-Thread: Backup → Download → Verify → Replace → Watcher → Restart"""
    global _UPDATE_STATUS
    app_path   = os.path.abspath(__file__)
    backup_path = app_path + ".bak"
    tmp_path    = app_path + ".new"

    def _set(state, message, progress):
        _UPDATE_STATUS["state"]    = state
        _UPDATE_STATUS["message"]  = message
        _UPDATE_STATUS["progress"] = progress

    try:
        # 1 ── Backup erstellen ────────────────────────────────────────────────
        _set("running", "Erstelle Backup der aktuellen Version…", 10)
        shutil.copy2(app_path, backup_path)

        # 2 ── Neue Version laden ──────────────────────────────────────────────
        _set("running", "Lade neue Version von GitHub…", 30)
        req = urllib.request.Request(
            _GITHUB_RAW_URL,
            headers={"User-Agent": "zisterne-monitor-updater"}
        )
        with urllib.request.urlopen(req, timeout=20) as r:
            new_content = r.read()

        with open(tmp_path, "wb") as f:
            f.write(new_content)

        # 3 ── Verifizieren ────────────────────────────────────────────────────
        _set("running", "Prüfe heruntergeladene Datei…", 55)
        try:
            text = new_content.decode("utf-8")
        except UnicodeDecodeError:
            raise ValueError("Datei ist kein gültiger UTF-8 Text")
        if "Flask" not in text or "__version__" not in text:
            raise ValueError("Ungültige Datei – Flask oder __version__ fehlt")
        if len(text) < 50_000:
            raise ValueError(f"Datei zu klein ({len(text)} Bytes) – vermutlich unvollständig")

        # 4 ── Installieren ────────────────────────────────────────────────────
        _set("running", "Installiere neue Version…", 75)
        shutil.move(tmp_path, app_path)
        os.chmod(app_path, 0o755)

        # 5 ── Rollback-Watcher starten (überlebt den Service-Neustart) ────────
        _set("running", "Starte Rollback-Watcher…", 85)
        q_bak = shlex.quote(backup_path)
        q_app = shlex.quote(app_path)
        rollback_script = (
            "#!/bin/bash\n"
            "sleep 40\n"
            "if ! systemctl is-active --quiet zisterne.service; then\n"
            f'    echo "$(date): Update fehlgeschlagen – Rollback" >> /var/log/zisterne_update.log\n'
            f"    cp -f {q_bak} {q_app}\n"
            "    systemctl restart zisterne.service\n"
            f'    echo "$(date): Rollback abgeschlossen" >> /var/log/zisterne_update.log\n'
            "else\n"
            f'    echo "$(date): Update v{__version__} erfolgreich" >> /var/log/zisterne_update.log\n'
            "fi\n"
        )
        with open("/tmp/zisterne_rollback.sh", "w") as f:
            f.write(rollback_script)
        os.chmod("/tmp/zisterne_rollback.sh", 0o755)
        subprocess.Popen(
            ["bash", "/tmp/zisterne_rollback.sh"],
            start_new_session=True,
            stdout=open("/tmp/zisterne_rollback.log", "w"),
            stderr=subprocess.STDOUT
        )

        # 6 ── Service neu starten ─────────────────────────────────────────────
        _set("restarting", "Dienst wird neu gestartet…", 95)
        time.sleep(0.8)  # Antwort noch zum Browser senden
        subprocess.Popen(["systemctl", "restart", "zisterne.service"])

    except Exception as exc:
        # Fehler → Rollback falls Backup vorhanden
        rb = ""
        if os.path.exists(backup_path):
            try:
                shutil.copy2(backup_path, app_path)
                rb = " · Backup wiederhergestellt"
            except Exception as rb_exc:
                rb = f" · Rollback fehlgeschlagen: {rb_exc}"
        if os.path.exists(tmp_path):
            try: os.remove(tmp_path)
            except Exception: pass
        _set("error", f"{exc}{rb}", 0)


STYLES = """
<link rel="preconnect" href="https://fonts.googleapis.com">
<link href="https://fonts.googleapis.com/css2?family=DM+Sans:wght@300;400;500;600&family=DM+Mono:wght@400;500&display=swap" rel="stylesheet">
<style>
:root{--bg:#f0f4f8;--sf:#fff;--sf2:#f7fafc;--bd:rgba(0,0,0,0.07);--tx:#0d1b2a;--tx2:#4a5568;--mu:#94a3b8;--bl:#0ea5e9;--bdk:#0369a1;--bls:rgba(14,165,233,.10);--tl:#06b6d4;--gn:#10b981;--gns:rgba(16,185,129,.10);--am:#f59e0b;--ams:rgba(245,158,11,.10);--rd:#ef4444;--rds:rgba(239,68,68,.10);--sh1:0 1px 3px rgba(0,0,0,.06);--sh2:0 4px 16px rgba(0,0,0,.08);--sh3:0 12px 40px rgba(0,0,0,.10);--rm:18px;--rl:24px;}
@media(prefers-color-scheme:dark){:root{--bg:#070d14;--sf:#0f1923;--sf2:#162030;--bd:rgba(255,255,255,.06);--tx:#e8f0f8;--tx2:#8ba3bc;--mu:#3d5270;--bls:rgba(14,165,233,.15);--gns:rgba(16,185,129,.12);--ams:rgba(245,158,11,.12);--rds:rgba(239,68,68,.12);--sh1:0 1px 3px rgba(0,0,0,.3);--sh2:0 4px 16px rgba(0,0,0,.35);--sh3:0 12px 40px rgba(0,0,0,.5);}}
*,*::before,*::after{box-sizing:border-box;margin:0;padding:0}
body{background:var(--bg);color:var(--tx);font-family:'DM Sans',-apple-system,sans-serif;font-size:15px;line-height:1.5;min-height:100vh;-webkit-font-smoothing:antialiased}
.wrap{max-width:1080px;margin:0 auto;padding:32px 20px 80px}
.hdr{display:flex;align-items:flex-start;justify-content:space-between;margin-bottom:36px}
.hdr h1{font-size:clamp(1.6rem,4vw,2.2rem);font-weight:600;letter-spacing:-.6px}
.hdr p{font-size:.85rem;color:var(--mu);margin-top:3px;font-family:'DM Mono',monospace}
.live{display:flex;align-items:center;gap:7px;padding:7px 14px;background:var(--gns);border:1px solid rgba(16,185,129,.2);border-radius:100px;font-size:.78rem;font-weight:500;color:var(--gn)}
.ldot{width:6px;height:6px;background:var(--gn);border-radius:50%;animation:lpulse 2s ease-in-out infinite}
@keyframes lpulse{0%,100%{opacity:1;transform:scale(1)}50%{opacity:.4;transform:scale(.7)}}
.tabs{display:flex;gap:4px;background:var(--sf);border:1px solid var(--bd);padding:4px;border-radius:var(--rm);width:fit-content;box-shadow:var(--sh1);margin-bottom:28px}
.tab{padding:8px 18px;border-radius:calc(var(--rm) - 4px);font-size:.875rem;font-weight:500;color:var(--tx2);cursor:pointer;border:none;background:transparent;font-family:'DM Sans',sans-serif;transition:all .2s;text-decoration:none}
.tab.a{background:var(--bl);color:#fff;font-weight:600}
.tab:hover:not(.a){background:var(--sf2);color:var(--tx)}
.card{background:var(--sf);border:1px solid var(--bd);border-radius:var(--rl);box-shadow:var(--sh3);margin-bottom:20px;animation:fu .4s ease both;overflow:hidden}
.cc{background:var(--sf);border:1px solid var(--bd);border-radius:var(--rl);box-shadow:var(--sh2);padding:24px;margin-bottom:20px;animation:fu .5s .1s ease both}
.ch{display:flex;align-items:flex-start;justify-content:space-between;margin-bottom:20px;gap:12px;flex-wrap:wrap}
.ct{font-size:1rem;font-weight:600;letter-spacing:-.2px}
.cs{font-size:.8rem;color:var(--mu);margin-top:2px}
.cw{position:relative;height:200px}
.g2{display:grid;grid-template-columns:1fr 1fr;gap:18px;margin-bottom:18px}
@media(max-width:680px){.g2{grid-template-columns:1fr}}
.tp{display:flex;gap:3px;background:var(--sf2);border:1px solid var(--bd);padding:3px;border-radius:12px}
.tpb{padding:5px 12px;border-radius:8px;font-size:.78rem;font-weight:500;color:var(--tx2);cursor:pointer;border:none;background:transparent;font-family:'DM Sans',sans-serif;transition:all .18s;white-space:nowrap}
.tpb.a{background:var(--bl);color:#fff;font-weight:600;box-shadow:0 2px 8px rgba(14,165,233,.3)}
.tpb:hover:not(.a){background:var(--sf);color:var(--tx)}
.sg{margin-bottom:8px}
.sgl{font-size:.75rem;font-weight:600;color:var(--mu);text-transform:uppercase;letter-spacing:.5px;margin-bottom:8px;padding:0 4px}
.sc{background:var(--sf);border:1px solid var(--bd);border-radius:var(--rl);box-shadow:var(--sh1);overflow:hidden;margin-bottom:16px}
.sr{display:flex;align-items:center;justify-content:space-between;padding:16px 22px;border-bottom:1px solid var(--bd);gap:16px}
.sr:last-child{border-bottom:none}
.si{flex:1}.sl{font-size:.95rem;font-weight:500}.sd{font-size:.78rem;color:var(--mu);margin-top:3px;line-height:1.4}
.si2{display:flex;align-items:center;gap:8px;flex-shrink:0}
input[type=number],input[type=text]{width:110px;padding:9px 12px;border-radius:10px;border:1.5px solid var(--bd);background:var(--bg);color:var(--tx);font-size:.95rem;font-family:inherit;outline:none;transition:border-color .2s;text-align:right;-webkit-appearance:none}
input[type=text]{width:200px;text-align:left}
input:focus{border-color:var(--bl)}
.ul{font-size:.85rem;color:var(--mu);min-width:28px}
.btn{display:inline-flex;align-items:center;justify-content:center;padding:10px 18px;border-radius:12px;border:none;font-size:.9rem;font-weight:600;font-family:inherit;cursor:pointer;transition:opacity .2s}
.btn:active{opacity:.75}
.bb{background:var(--bl);color:#fff}
.br{background:var(--rds);color:var(--rd)}
.bg{background:var(--gns);color:var(--gn)}
.al{padding:14px 18px;border-radius:14px;font-size:.875rem;margin-bottom:16px;font-weight:500;animation:fu .3s ease}
.alo{background:var(--gns);color:var(--gn)}
.ale{background:var(--rds);color:var(--rd)}
.cb{background:var(--bls);border-radius:16px;padding:20px 22px;margin-bottom:16px;border:1px solid rgba(14,165,233,.15)}
.cb h3{font-size:1rem;font-weight:600;margin-bottom:6px;color:var(--bl)}
.cb p{font-size:.85rem;color:var(--mu);line-height:1.5}
.clive{display:flex;align-items:flex-start;gap:24px;margin-top:14px;flex-wrap:wrap}
.clv{font-size:1.8rem;font-weight:700;letter-spacing:-1px;font-variant-numeric:tabular-nums}
.cll{font-size:.75rem;color:var(--mu);margin-top:2px}
table{width:100%;border-collapse:collapse;font-size:.85rem}
th{text-align:left;color:var(--mu);font-weight:500;font-size:.75rem;text-transform:uppercase;letter-spacing:.4px;padding:0 0 12px}
td{padding:11px 0;border-bottom:1px solid var(--bd);font-variant-numeric:tabular-nums}
tr:last-child td{border-bottom:none}
td:not(:first-child){text-align:right;font-weight:500}
footer{margin-top:40px;text-align:center;font-size:.75rem;color:var(--mu);font-family:'DM Mono',monospace;border-top:1px solid var(--bd);padding-top:20px}
@keyframes fu{from{opacity:0;transform:translateY(12px)}to{opacity:1;transform:translateY(0)}}
/* ── Querschnitt Zisterne ─────────────────────────────── */
.mi{display:grid;grid-template-columns:1fr 1fr}
@media(max-width:680px){.mi{grid-template-columns:1fr}}
.wp{
  position:relative;min-height:420px;overflow:hidden;
  background:linear-gradient(180deg,#c9e8f5 0%,#b8ddf0 18%,#5a9e3f 18%,#4a8a30 23%,#7a5330 23%,#6b4525 42%,#5c3a1c 70%,#4a2e12 100%);
  border-radius:var(--rl) 0 0 var(--rl);
}
@media(max-width:680px){.wp{border-radius:var(--rl) var(--rl) 0 0;min-height:360px}}
.wp::before{
  content:'';position:absolute;top:18%;left:0;right:0;height:5%;
  background:radial-gradient(ellipse 3px 6px at 8% 50%,#3d7a25 0%,transparent 100%),radial-gradient(ellipse 2px 5px at 15% 30%,#4a8a30 0%,transparent 100%),radial-gradient(ellipse 3px 7px at 22% 60%,#3d7a25 0%,transparent 100%),radial-gradient(ellipse 2px 5px at 30% 40%,#4d8f33 0%,transparent 100%),radial-gradient(ellipse 3px 6px at 38% 55%,#3d7a25 0%,transparent 100%),radial-gradient(ellipse 2px 4px at 50% 30%,#4a8a30 0%,transparent 100%),radial-gradient(ellipse 3px 7px at 62% 60%,#3d7a25 0%,transparent 100%),radial-gradient(ellipse 2px 5px at 72% 35%,#4a8a30 0%,transparent 100%),radial-gradient(ellipse 3px 6px at 82% 55%,#3d7a25 0%,transparent 100%),radial-gradient(ellipse 2px 4px at 92% 40%,#4d8f33 0%,transparent 100%);
  pointer-events:none;z-index:2;
}
.wp::after{
  content:'';position:absolute;top:23%;left:0;right:0;bottom:0;
  background:radial-gradient(ellipse 4px 3px at 7% 20%,rgba(90,50,20,.4) 0%,transparent 100%),radial-gradient(ellipse 3px 4px at 18% 45%,rgba(80,40,15,.3) 0%,transparent 100%),radial-gradient(ellipse 5px 3px at 28% 65%,rgba(70,35,12,.35) 0%,transparent 100%),radial-gradient(ellipse 3px 5px at 83% 30%,rgba(90,50,20,.4) 0%,transparent 100%),radial-gradient(ellipse 4px 3px at 90% 55%,rgba(80,40,15,.3) 0%,transparent 100%),radial-gradient(ellipse 3px 4px at 76% 70%,rgba(70,35,12,.35) 0%,transparent 100%);
  pointer-events:none;z-index:2;
}
.fill-indicator{
  position:absolute;top:7px;left:50%;transform:translateX(-50%);
  background:rgba(255,255,255,.92);backdrop-filter:blur(8px);-webkit-backdrop-filter:blur(8px);
  border-radius:12px;padding:7px 16px 8px;min-width:210px;text-align:center;
  box-shadow:0 2px 12px rgba(0,0,0,.12);z-index:30;white-space:nowrap;
}
@media(max-width:680px){
  .fill-indicator{left:auto;right:8px;transform:none;min-width:160px;padding:6px 12px 7px;}
}
.fi-title{font-size:.7rem;color:#666;margin-bottom:5px;letter-spacing:.2px}
.fi-title strong{color:#0d1b2a}
.fi-bar{height:7px;background:#e0e0e0;border-radius:4px;overflow:hidden}
.fi-bar-inner{height:100%;background:linear-gradient(90deg,#0ea5e9,#38bdf8);border-radius:4px;transition:width 1s}
.pipe-v-left{
  position:absolute;width:10px;
  background:linear-gradient(90deg,#8a9ab0,#b8c8dc,#8a9ab0);
  border-radius:2px;box-shadow:1px 0 3px rgba(0,0,0,.2);z-index:5;
}
.pipe-v-left::after{
  content:'';position:absolute;bottom:0;left:50%;transform:translateX(-50%);
  width:3px;height:8px;background:linear-gradient(180deg,transparent,rgba(100,200,255,.8));
  border-radius:0 0 50% 50%;animation:drip 2s ease-in-out infinite;
}
@keyframes drip{0%,100%{opacity:0;transform:translateX(-50%) scaleY(0)}60%{opacity:1;transform:translateX(-50%) scaleY(1)}}
.pipe-h-left{
  position:absolute;height:10px;
  background:linear-gradient(180deg,#8a9ab0,#b8c8dc,#8a9ab0);
  border-radius:2px 0 0 2px;box-shadow:0 1px 3px rgba(0,0,0,.2);z-index:5;
}
.cist-wrap{position:absolute;left:12%;right:12%;top:21%;bottom:3%;z-index:4;}
.cist-wall{
  position:absolute;inset:0;
  border-radius:50% 50% 50% 50%/20% 20% 20% 20%;
  background:radial-gradient(ellipse at 35% 30%,#c0c8d0,#8a9299 50%,#6e7880 100%);
  border:2px solid #9aabb8;
  box-shadow:inset 0 4px 15px rgba(0,0,0,.25),inset 0 -4px 10px rgba(0,0,0,.15),0 6px 24px rgba(0,0,0,.45);
}
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

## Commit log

2026-03-27 Initial release: Zisterne Monitor v0.5.0
    [1_Gehaeuse_Unterteil.scad, 2_Gehaeuse_Deckel.scad, 3_Sensor_Rohrhalterung_DN25.scad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]
2026-03-27 Add files via upload
    Anpassung an die korrekte Größe des Sensors
    [sensor_wandhalterung_korrigiert_plan_mit_langloch_v2.scad, sensor_wandhalterung_korrigiert_plan_mit_langloch_v2.stl]
2026-03-30 Zisterne: 3D-Zylinder durch Querschnitt-Darstellung ersetzt
    Neue Visualisierung zeigt die Zisterne als realistischen Erdquerschnitt:
    - Hintergrund mit Himmel, Gras und Erdreich
    - Betonzisterne als ovaler Querschnitt mit Schachtdeckel
    - Beschriftete Rohre: Zulauf vom Dach, Überlauf, Entnahme mit Pumpe
    - Füllstandsbalken oben mit Prozentwert
    - Wasser-Animation und Blasen bleiben erhalten
    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
2026-03-31 fix: Live-Kalibrierung liest direkt vom Sensor (v0.5.2)
    [app.py]
2026-03-31 fix: Pumpen-Label von 'P' zu 'Pumpe' (v0.5.3)
    [app.py]
2026-04-01 feat: SR04M-2 UART support (v0.6.0)
    Replace JSN-SR04T GPIO trigger/echo with SR04M-2 UART serial protocol.
    - Remove RPi.GPIO dependency, add pyserial
    - Replace abstand_messen() with UART read (0x01 cmd, 4-byte response)
    - Replace trig_pin/echo_pin config with serial_port
    - Update settings page accordingly
    [app.py]
2026-04-01 feat: headless UART enable + serial_port config (v0.6.0)
2026-04-01 docs: update VERSION to 0.6.0 SR04M-2 UART
2026-04-01 docs: update README for SR04M-2 UART sensor v0.6.0
2026-04-01 fix: add dtoverlay=disable-bt for reliable PL011 UART on Pi Zero 2W
2026-04-06 Release v0.7.0: UART Auto-Output-Modus, robuste Port-Verwaltung, Docs überarbeitet
    - UART Auto-Output-Modus (kein Trigger-Befehl mehr)
    - _parse_uart_frame() mit Checksum-Verifizierung (FF H L SUM)
    - _open/_close/_reopen_serial() für robuste Port-Verwaltung
    - Automatischer Port-Reopen bei UART-Fehler
    - firstboot.sh: config.json mit allen Feldern (kapazitaet_l, Wetterfelder)
    - README: SR04M-2 UART-Verkabelung, korrekter Tech Stack
    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
2026-04-07 Release v0.7.1: Auto-Update mit Backup & automatischem Rollback
    - Neue Sektion "Software-Update" in Einstellungen
    - Ein-Klick-Update direkt von GitHub auf den Pi
    - Backup (app.py.bak) vor jedem Update
    - Rollback-Watcher als separater Prozess (überlebt Service-Neustart)
    - Automatischer Rollback nach 40s falls Service nicht startet
    - /api/update/check – vergleicht aktuelle vs. GitHub-Release-Version
    - /api/update/start – startet Update-Thread mit Fortschrittsanzeige
    - /api/update/status – polling für Echtzeit-Fortschrittsbalken
    - shlex.quote() für Shell-sichere Pfade im Rollback-Script
    - FIX: Plattform-Anzeige SR04M-2 UART (war JSN-SR04T)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
    [app.py]
2026-04-11 fix: Temporärer Swap in firstboot.sh verhindert OOM-Crash bei pip install
    512 MB Swap-Datei wird vor pip install angelegt und nach Setup wieder
    entfernt. Behebt Kernel-Panic (sysrq OOM-Kill) auf Pi Zero mit 512 MB RAM.
    [app.py]
2026-04-11 fix: WLAN autoconnect nach Captive Portal und API-Verbindung (v0.7.3)
    - Captive Portal und /api/wifi/connect setzen jetzt explizit
    connection.autoconnect=yes und autoconnect-priority=10
    - Pi verbindet sich nach Neustart/Stromausfall automatisch
    wieder mit dem über das Portal eingerichteten WLAN
    [app.py]
2026-04-11 fix: Kapazität ab 1L und Messintervall ab 1s einstellbar (v0.7.4)
    [app.py]
2026-04-11 fix: Update-Button JS SyntaxError – \n in confirm-Dialog korrekt escapen (v0.7.5)
    [app.py]
2026-04-11 fix: Dachfläche min. 1 m² (war 10 m²) – v0.7.6
    [app.py]
2026-04-13 fix: Zufluss-Erkennung filtert Sensorrauschen (v0.7.7)
    Einzelne Messdifferenzen wurden fälschlicherweise als Zufluss-Ereignisse
    gewertet. Ereignisse müssen jetzt mind. 3 aufeinanderfolgende steigende
    Messungen (~3 Min.) andauern und mind. 30 Liter Gesamtvolumen erreichen.
    [1_Gehaeuse_Unterteil.scad, 2_Gehaeuse_Deckel.scad, 3_Sensor_Rohrhalterung_DN25.scad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]
2026-04-14 v0.7.8: Fix sysrq-Flood durch fehlende ttyS0-Behandlung in firstboot.sh
    Serial-Konsole wird jetzt für alle Varianten entfernt (serial0, ttyAMA0, ttyS0).
    serial-getty wird für ttyAMA0 und ttyS0 deaktiviert.
    [app.py]
2026-04-14 fix: Überlappung Zulauf-Label / Füllstandsanzeige auf Mobil (v0.7.9)
    - Zulauf-Label wird via positionPipes() dynamisch auf Rohrhöhe positioniert
    → kein Overlap mehr mit fill-indicator egal bei welcher Screenbreite
    - Füllstandsanzeige auf Mobile nach rechts (right:8px) verschoben
    [app.py]

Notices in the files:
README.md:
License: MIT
